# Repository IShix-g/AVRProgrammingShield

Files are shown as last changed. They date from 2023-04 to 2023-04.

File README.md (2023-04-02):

AVR マイコンにスケッチを書き込む為のシールドです。
書き込み方式はISPとなります。

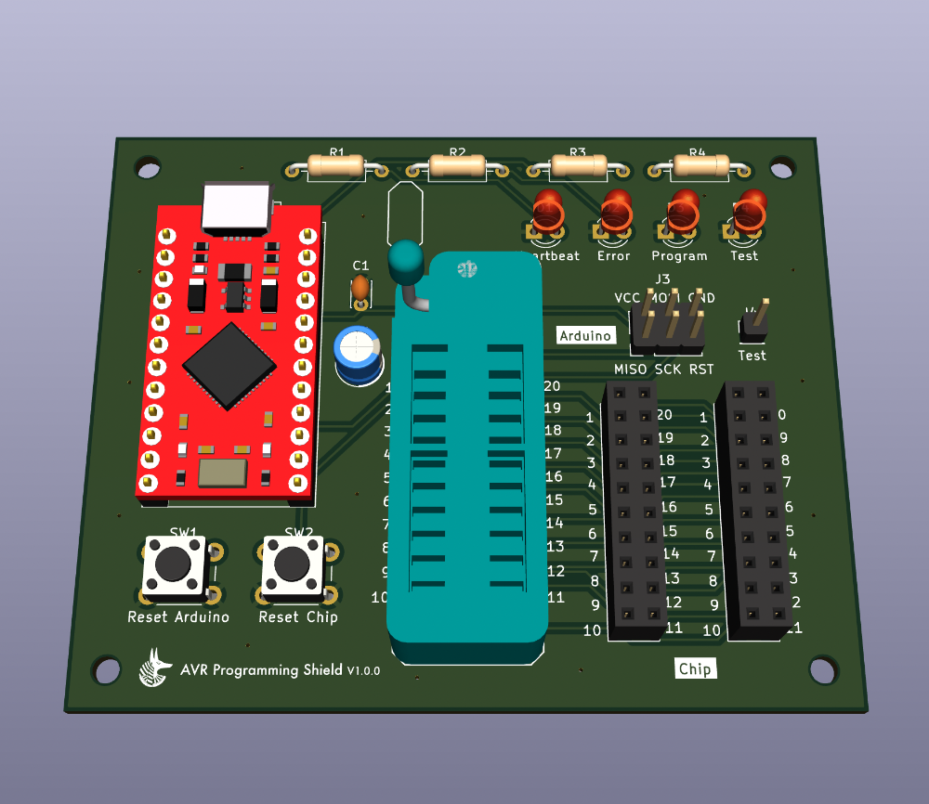
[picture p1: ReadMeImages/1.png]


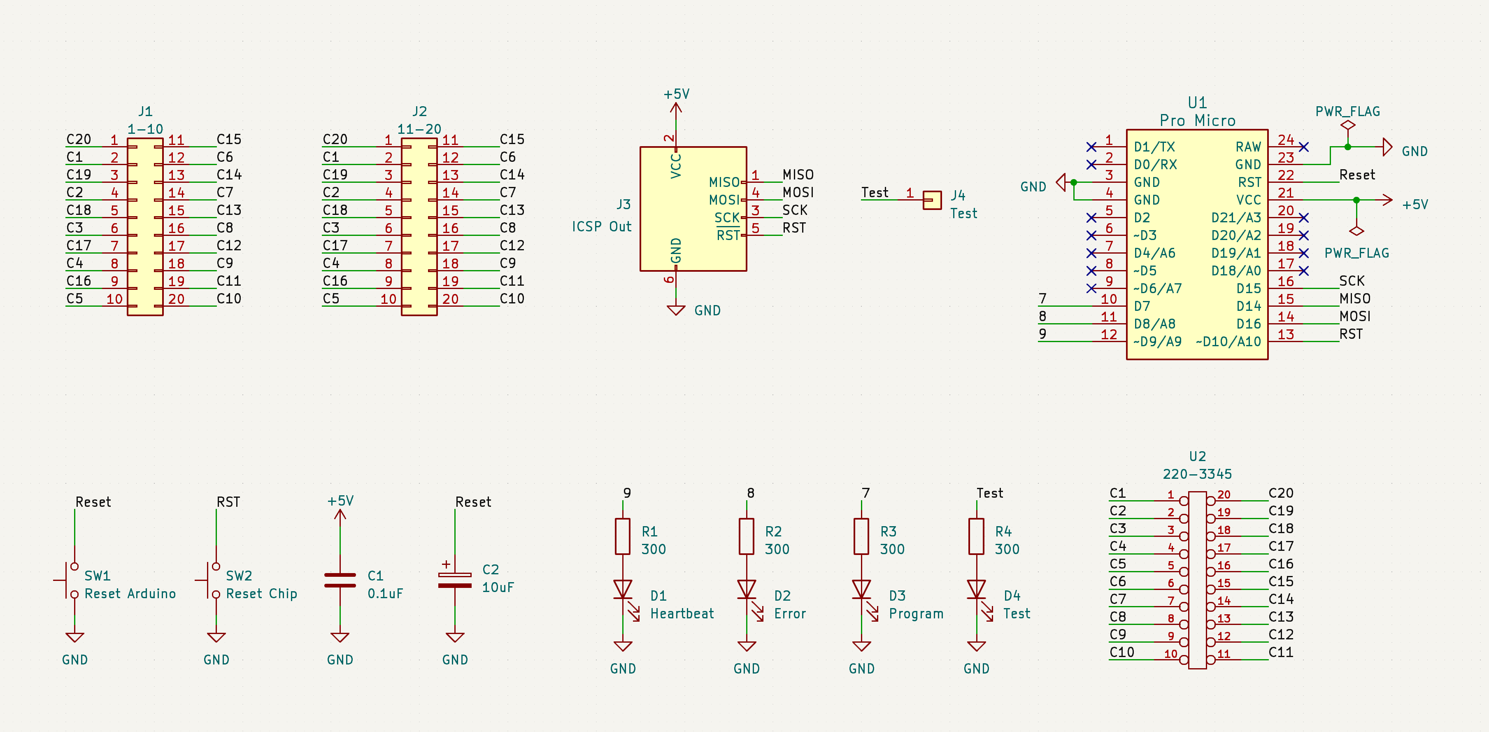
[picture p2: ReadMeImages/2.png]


# 使い方

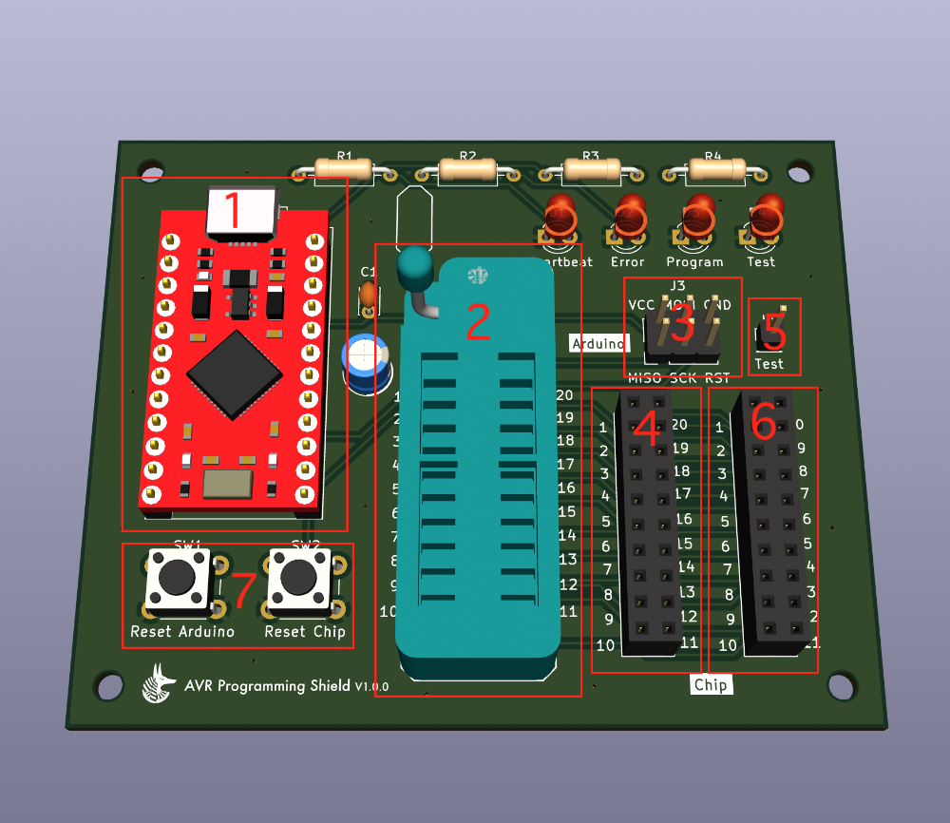
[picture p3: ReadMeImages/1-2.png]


## 1. Arduino Pro Microを設置

## 2. AVRマイコンを設置
レバー側を上として上に詰めるようにAVRマイコンを配置しレーバーを倒します。

## 3. ジャンパーケーブルを接続
すべてのピンにジャンパーケーブルを接続します。

## 4. AVRマイコンに合わせてジャンパーケーブルを接続
2のソケット左右に書かれた1-20の番号と4の1-20の番号は内部で接続されています。
例えば2のソケットの1番は、4の1と繋がっています。
3で接続したジャンパーピンをマイコンのデータシートを見ながら4の必要な番号に接続します。

### [接続例] ATiny2313
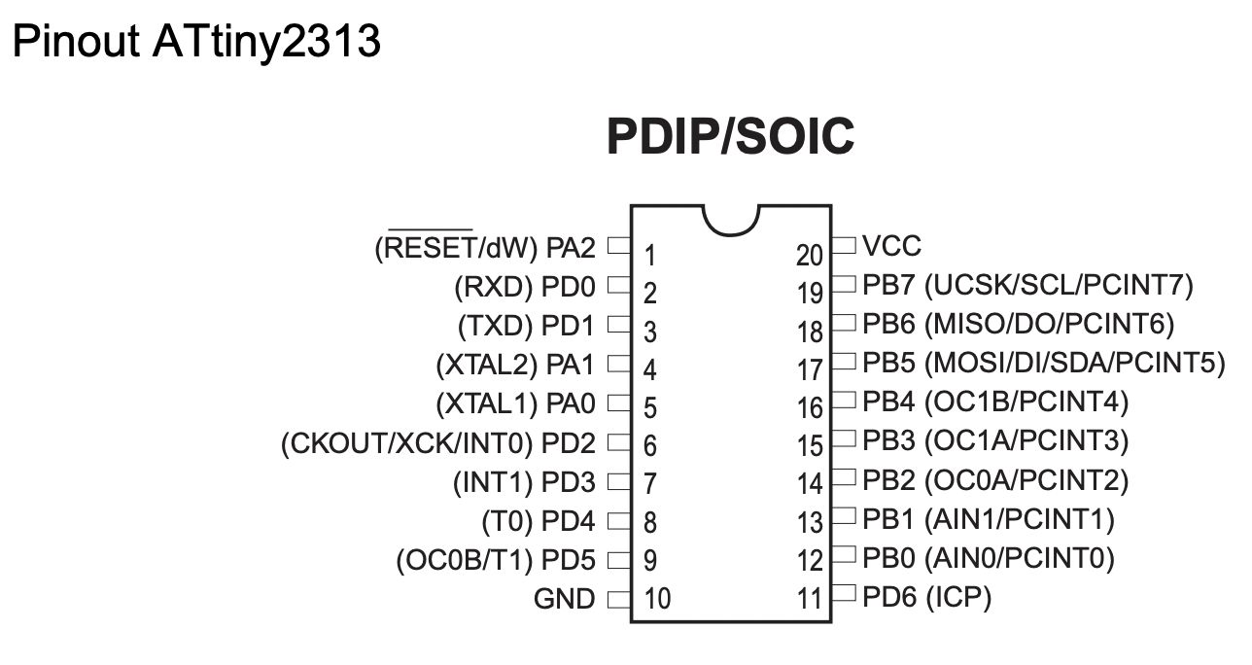
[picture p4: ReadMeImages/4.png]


| シールド | ATiny2313  |
|---|-----|
| VCC  | 20  |
| MOSI | 17  |
| GND  | 10  |
| MISO | 18  |
| SCK  | 19  |
| RST  | 1 |

## 5. LEDのテスト用ピン
LEDで正常に書き込めるかテストができます。

## 6. 外部出力
4の1-20と内部で接続されています。ブレッドボードなどと接続する用途で使えます。

## 7. リセットボタン

# 必要なパーツ

| リファレンス  | 名前 | サイズ/容量 | 数 |
|---|---|---|-----|
| U1 | Arduino Pro Micro | | 1 |
| C1 | セラミックコンデンサ | 104 (0.1uF) | 1 |
| C2 | 電解コンデンサ | 10uF | 1 |
| D1-D4 | LED | 3mm 5V | 4 |
| U2 | ZIF ソケット  | 2.54mmピッチ 20pin 300mil | 1 |
| R1-R4 | カーボン抵抗 | 300Ω前後 | 4 |
| SW1,Sw2 | タクトスイッチ | 5mm | 2 |
| J1 | ピンソケット | 2.54mmピッチ 2x10 | 2 |
| J2 | ピンソケット | 2.54mmピッチ 1x12 | 2 |
| J3 | ピンヘッダー | 2.54mmピッチ 2x3 | 1 |
| J4 | ピンヘッダー | 2.54mmピッチ 1x1 | 1 |

# その他の必要なもの

- ジャンパーケーブル(メス、オス) x 7

# スケッチの書き込み

## [初回のみ] Arduino Pro MicroにArduinoISPを書き込む

**File > Examples > 11.ArduinoISP**

普段通りスケッチを開いてアップロードボタンを押すだけです。
このシールドに載せたままでは書き込みできないので、載せずに書き込みしてください。
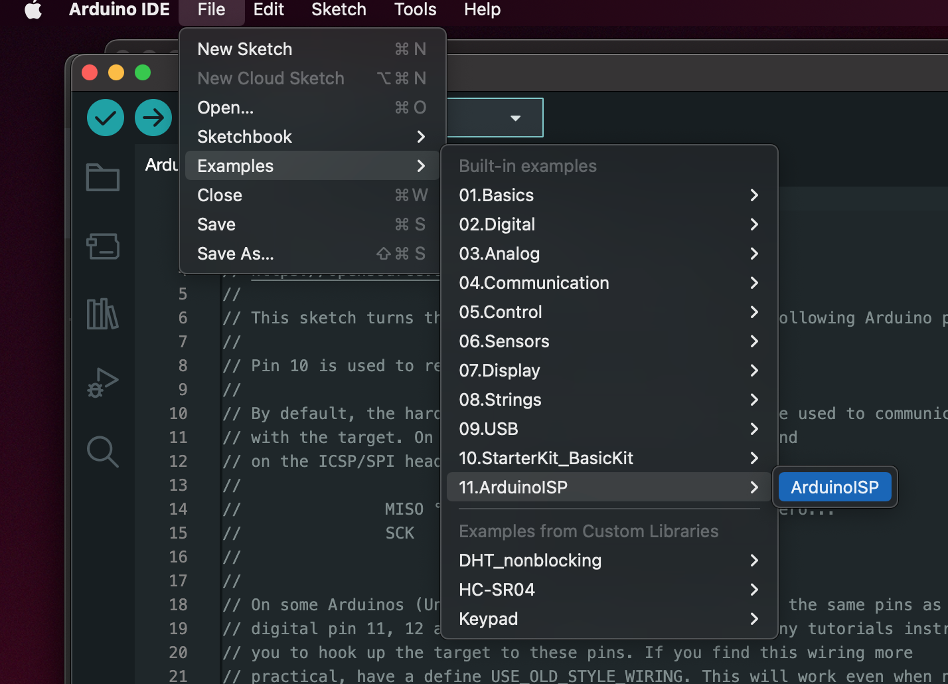
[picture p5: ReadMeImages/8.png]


## [初回のみ] ブートローダーを書き込みする
ブートローダーを書き込む為ではなく、クロック数を合わせる為に必要なようです。

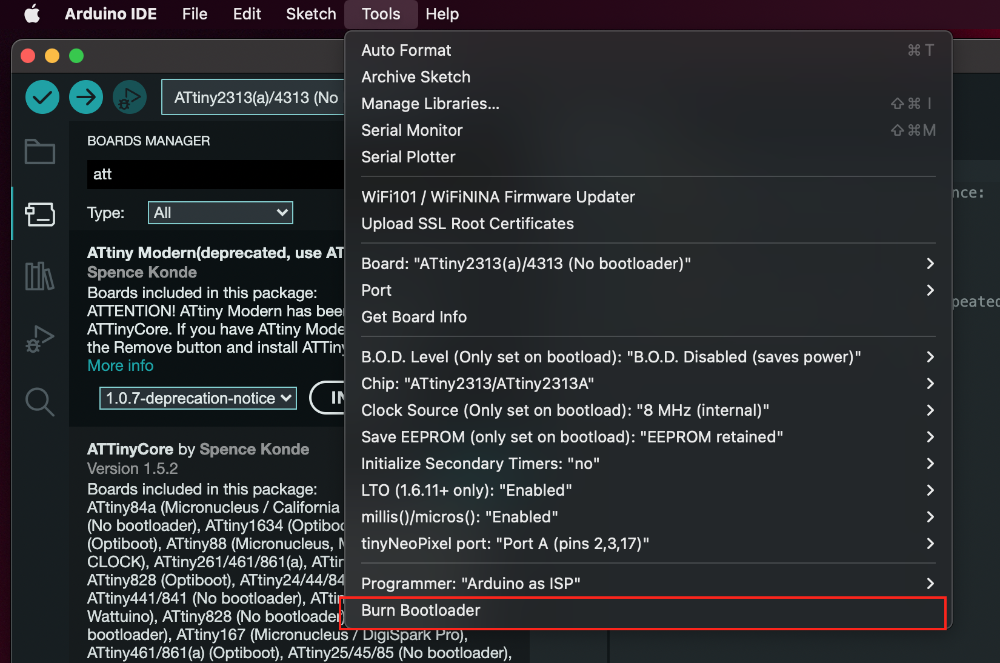
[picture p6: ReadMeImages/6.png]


## プログラマにArduino as ISPを選択する

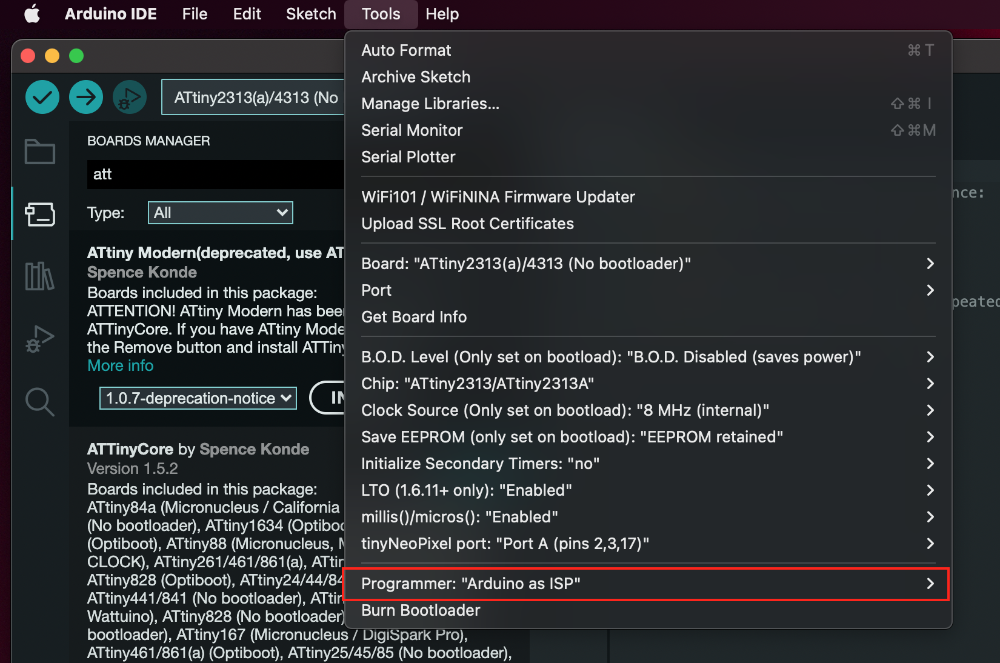
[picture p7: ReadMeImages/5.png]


## スケッチの書き込みの際はプログラマーを使ってアップロードで書き込みする

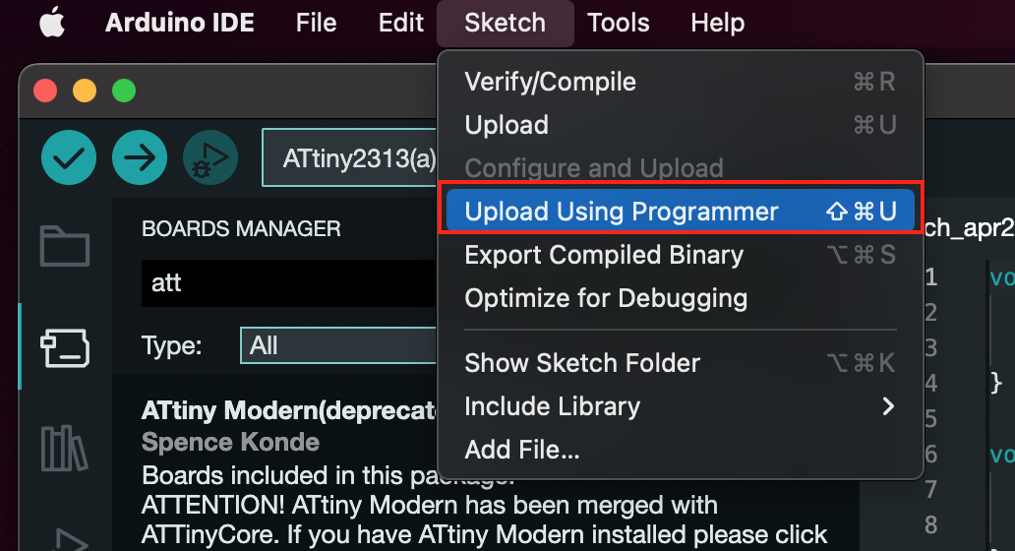
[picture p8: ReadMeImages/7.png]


# 基板の発注
[PCBWay](https://www.pcbway.jp/g/ug57q0)に注文する場合、対応するGerber Fileを利用できます。

- [ProgrammingShield V1.0.kicad_pcb.zip](ProgrammingShield V1.0.kicad_pcb.zip)

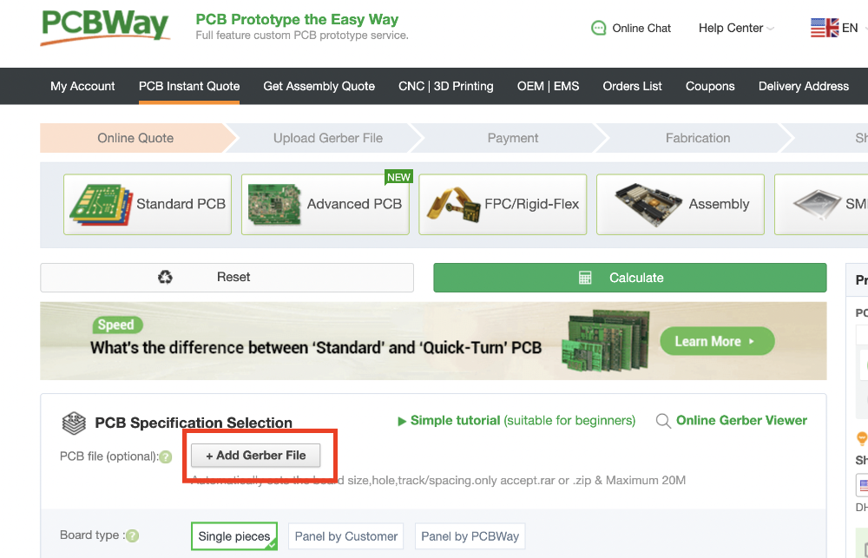
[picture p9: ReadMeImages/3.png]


## 修正したい場合
KiCad 7のデータがそのまま含まれています。ダウンロードして自由に修正してください。
開く前に下記2つのデータをインストールする必要があります。

- [ArduinoのKiCAD用ライブラリ公開](https://www.g200kg.com/archives/2020/11/arduinokicad.html)
- [kicad用ゼロプレッシャーICソケットの部品](http://ayabu.blog.shinobi.jp/kicad/kicad%E7%94%A8%E3%82%BC%E3%83%AD%E3%83%97%E3%83%AC%E3%83%83%E3%82%B7%E3%83%A3%E3%83%BCic%E3%82%BD%E3%82%B1%E3%83%83%E3%83%88%E3%81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)

## 修正した後に基板を発注したい場合

[PCBWay](https://www.pcbway.jp/g/ug57q0)に注文する場合、プラグイン&コンテンツマネージャーよりPCBWayのプラグインを導入するとワンクリックでGerber Fileの生成とzip圧縮、注文画面へのzip貼り付けを自動でやってくれるので便利です。

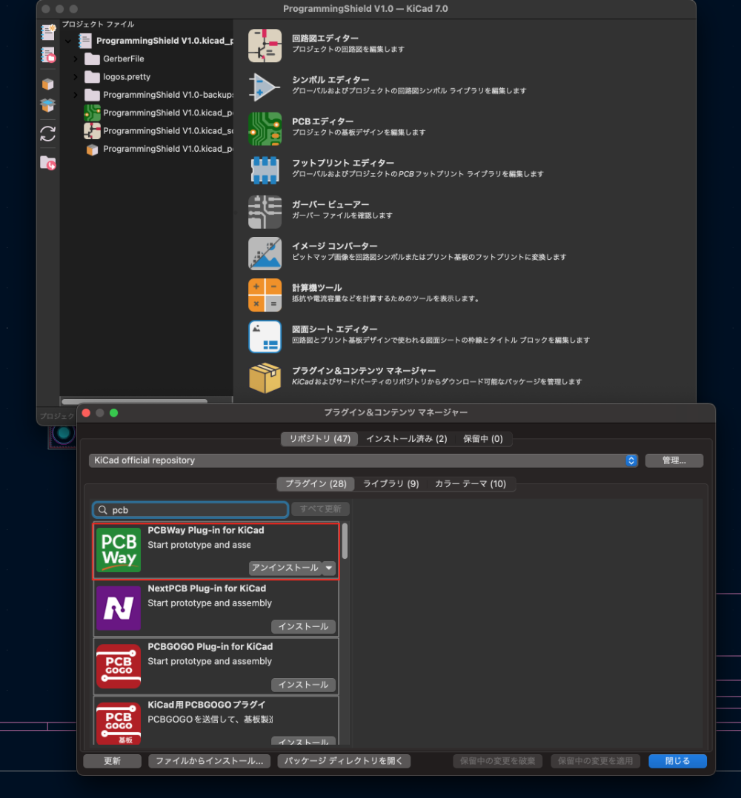
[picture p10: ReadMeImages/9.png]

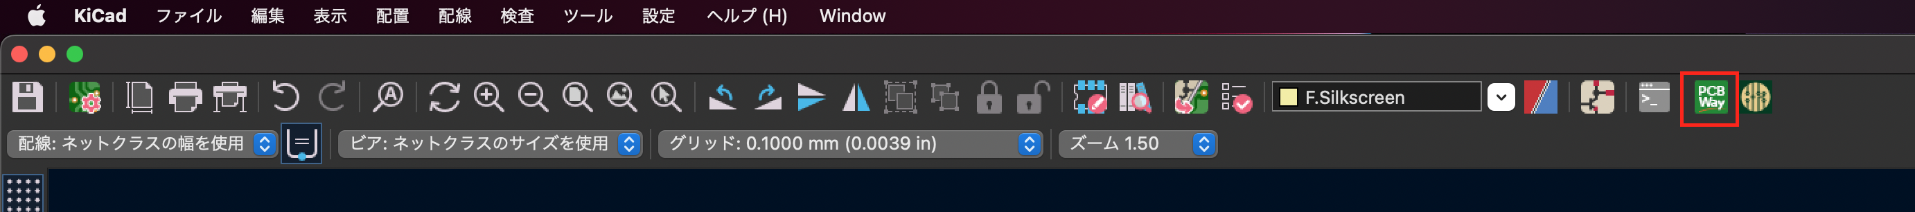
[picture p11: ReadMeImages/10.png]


# 動作確認済み AVRマイコン
- ATtiny 13A
- ATtiny 44A
- ATtiny 84A
- ATtiny 2313

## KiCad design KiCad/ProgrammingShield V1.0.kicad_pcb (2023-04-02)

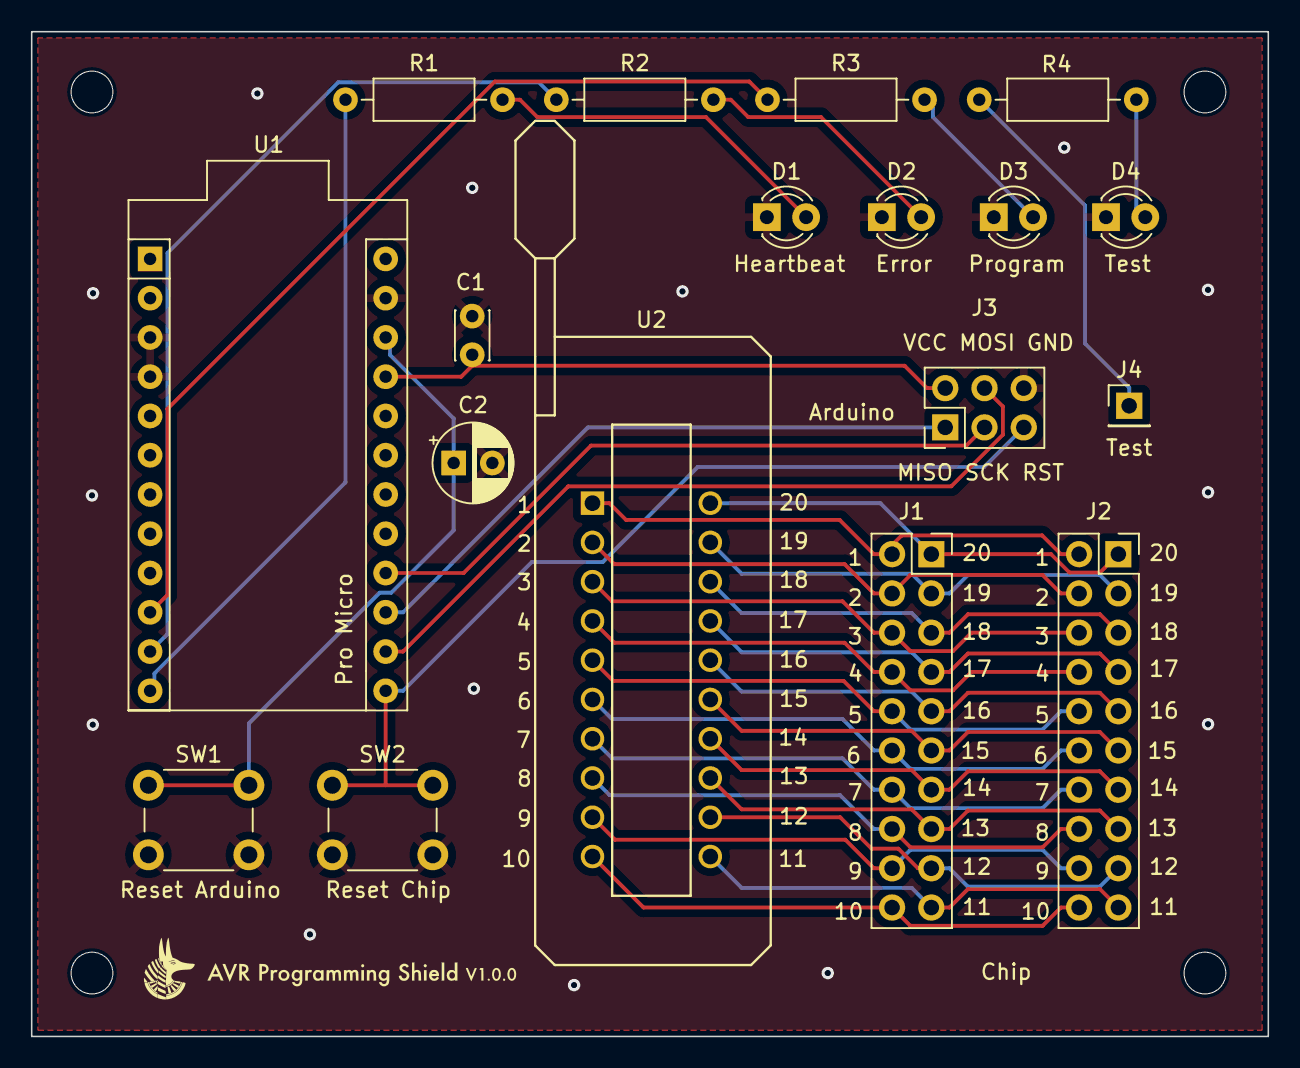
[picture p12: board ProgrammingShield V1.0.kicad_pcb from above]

Board: 2 copper layers, 80.0 x 65.0 mm, 22 parts (0 on the bottom side), 35 nets.

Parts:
C1: 0.1uF; C_Disc_D3.0mm_W2.0mm_P2.50mm
C2: 10uF; CP_Radial_D5.0mm_P2.50mm
D1: Heartbeat; LED_D3.0mm
D2: Error; LED_D3.0mm
D3: Program; LED_D3.0mm
D4: Test; LED_D3.0mm
H1, H2, H3, H4: MountingHole; MountingHole_2.7mm_M2.5
J1: 1-10; PinSocket_2x10_P2.54mm_Vertical
J2: 11-20; PinSocket_2x10_P2.54mm_Vertical
J3: ICSP Out; PinHeader_2x03_P2.54mm_Vertical
J4: Test; PinHeader_1x01_P2.54mm_Vertical
R1, R2, R3, R4: 300; R_Axial_DIN0207_L6.3mm_D2.5mm_P10.16mm_Horizontal
SW1: Reset Arduino; SW_PUSH_6mm
SW2: Reset Chip; SW_PUSH_6mm
U1: Pro Micro; Sparkfun_Pro_Micro
U2: 220-3345; 220-3342

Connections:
+5V: C1.1, J3.2 (VCC), U1.21 (VCC)
/7: R3.1, U1.10 (D7)
/8: R2.1, U1.11 (D8/A8)
/9: R1.1, U1.12 (~D9/A9)
/C1: J1.2, J2.2, U2.1
/C2: J1.4, J2.4, U2.2
/C3: J1.6, J2.6, U2.3
/C4: J1.8, J2.8, U2.4
/C5: J1.10, J2.10, U2.5
/C6: J1.12, J2.12, U2.6
/C7: J1.14, J2.14, U2.7
/C8: J1.16, J2.16, U2.8
/C9: J1.18, J2.18, U2.9
/C10: J1.20, J2.20, U2.10
/C11: J1.19, J2.19, U2.11
/C12: J1.17, J2.17, U2.12
/C13: J1.15, J2.15, U2.13
/C14: J1.13, J2.13, U2.14
/C15: J1.11, J2.11, U2.15
/C16: J1.9, J2.9, U2.16
/C17: J1.7, J2.7, U2.17
/C18: J1.5, J2.5, U2.18
/C19: J1.3, J2.3, U2.19
/C20: J1.1, J2.1, U2.20
/MISO: J3.1 (MISO), U1.15 (D14)
/MOSI: J3.4 (MOSI), U1.14 (D16)
/RST: J3.5 (~RST), SW2.1 (A), U1.13 (~D10/A10)
/Reset: C2.1, SW1.1 (A), U1.22 (RST)
/SCK: J3.3 (SCK), U1.16 (D15)
/Test: J4.1, R4.1
GND: C1.2, C2.2, D1.1 (K), D2.1 (K), D3.1 (K), D4.1 (K), J3.6 (GND), SW1.2 (A), SW2.2 (A), U1.3 (GND), U1.4 (GND), U1.23 (GND)
unnamed: D1.2 (A), R1.2
unnamed: D2.2 (A), R2.2
unnamed: D3.2 (A), R3.2
unnamed: D4.2 (A), R4.2
